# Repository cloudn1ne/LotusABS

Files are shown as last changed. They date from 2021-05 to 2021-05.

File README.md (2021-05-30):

# LotusABS

<table border=0>
<tr>
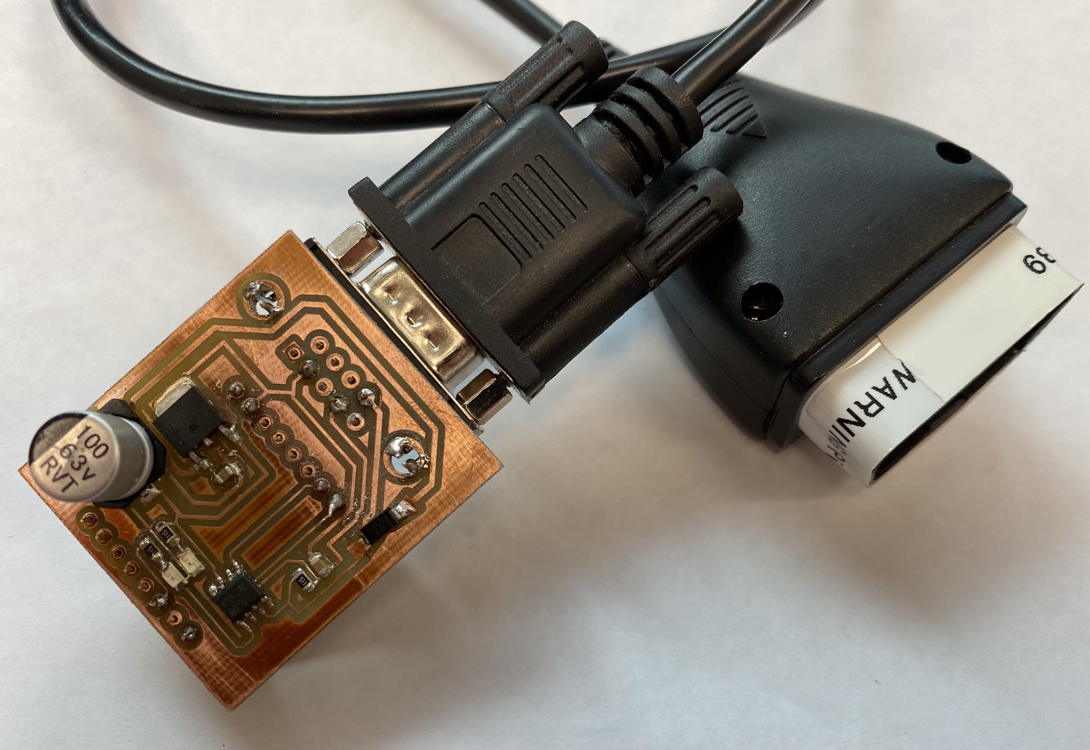
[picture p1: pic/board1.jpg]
<td></td>
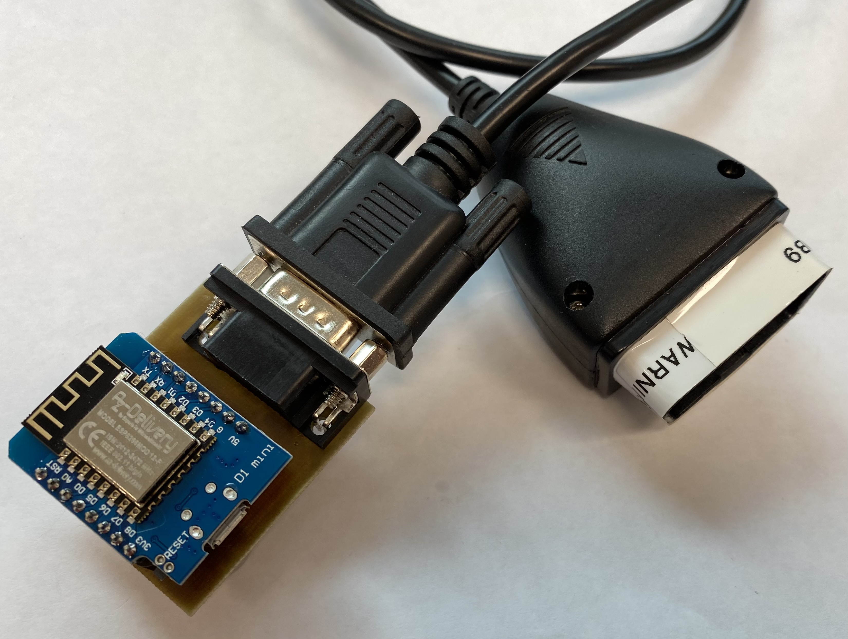
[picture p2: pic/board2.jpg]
<td colspan=2></td>
</tr><tr>
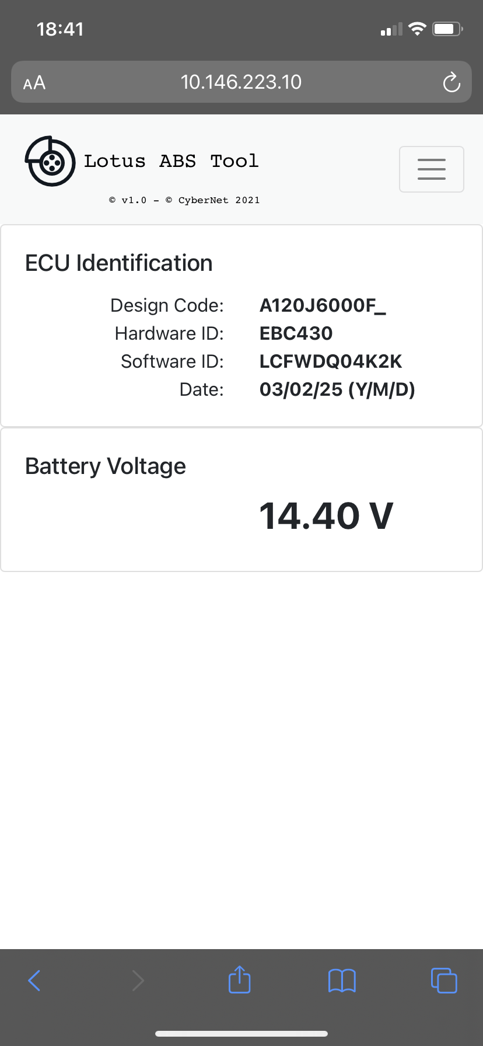
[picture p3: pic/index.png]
<td></td>
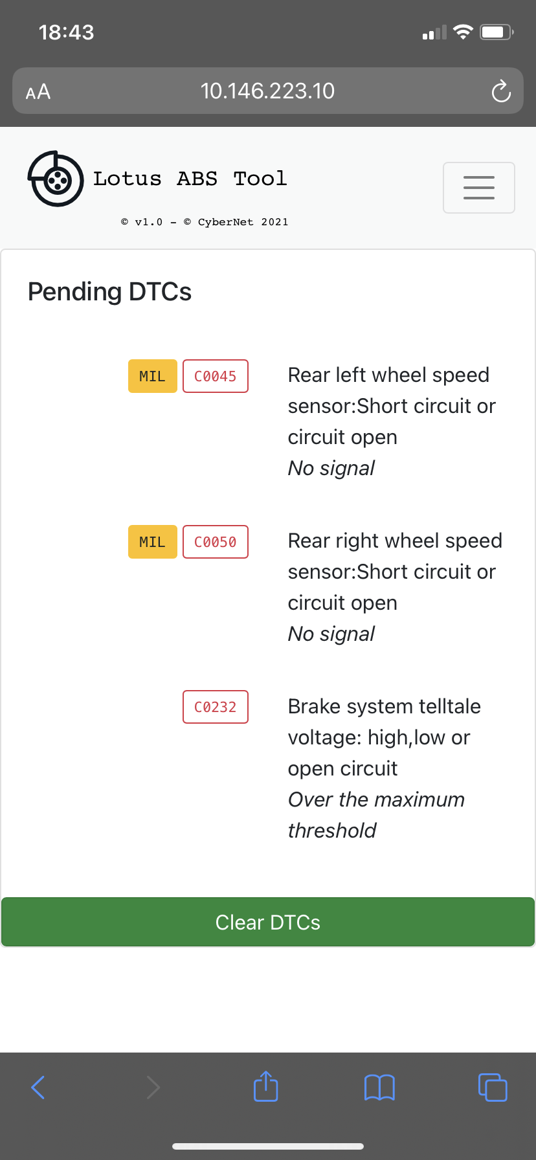
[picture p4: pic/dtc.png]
<td></td>
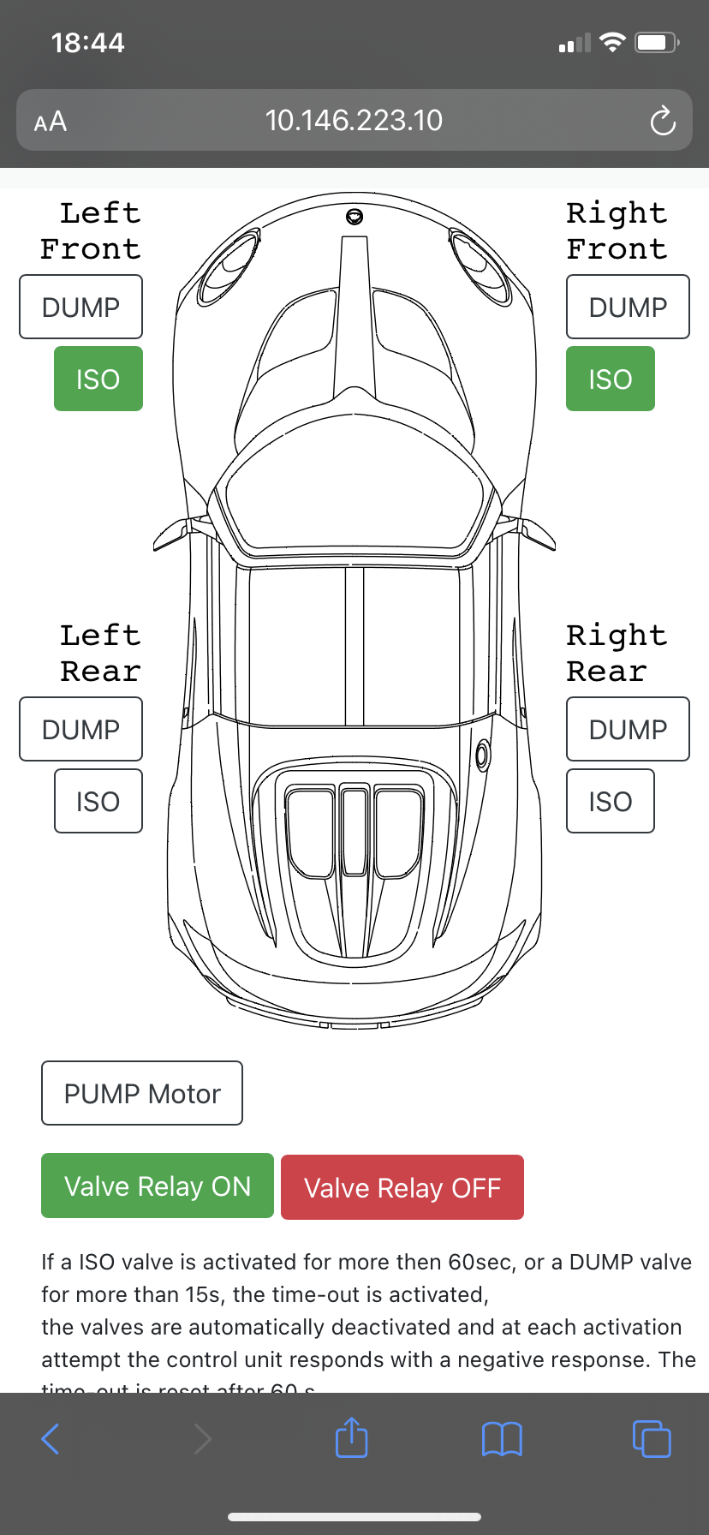
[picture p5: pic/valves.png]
<td></td>
</tr>
</table>

## What can you do with it ?

The software part is a pretty minimum implementation of the KWP2000 via K-LINE as used by the EBC430 EBC.
The supported Service IDs are:

Function | Usage
-------- | -----
StartCommunication | start a KWP2000 session
ReadECUIdentification | ECU details, nothing new here - same as listed in the Lotus Service Manual
ReadDataByLocalId | battery voltage, wheel speeds (not implemented, because my car is not moving atm)
ReadDiagnosticTroubleCodeByStatus | read DTC codes and status reasons
ClearDiagnosticInformationService | clear and DTCs
InputOutputControlByLocalId | control the valves, pump, relay

So with that you can establish communication with the ECU, get software/hardware versions, battery voltage (wheels speeds later on), read and clear DTCs, and most importantly
control the valves, pump and valve relay to aid with bleeding.

## How can i use it ?

You need to solder up the little ESP8266 based adapter (or put it on breadboard if you are adventurous. A proven PCB design and circuit is included in the ./pcb folder.
It was made with KiCAD (www.kicad.org)

## Whats the difference to existing KLINE/OBD Tools ?

Not much - i didnt have one, so i had to roll my own - the most notible difference is that the KLINE line has to be on PIN #12 of the OBD connector (usualy it would be Pin #7)
And you wont have a GUI to control stuff.

## Software
The project is based on PLATFORM.IO - download VS Code and install platform IO (https://platformio.org/) 

## Hardware
see KiCAD

### As usual that tool comes with no warranty, it might blow up your airbags (same KLINE) or set your car on fire. Good luck ;-)

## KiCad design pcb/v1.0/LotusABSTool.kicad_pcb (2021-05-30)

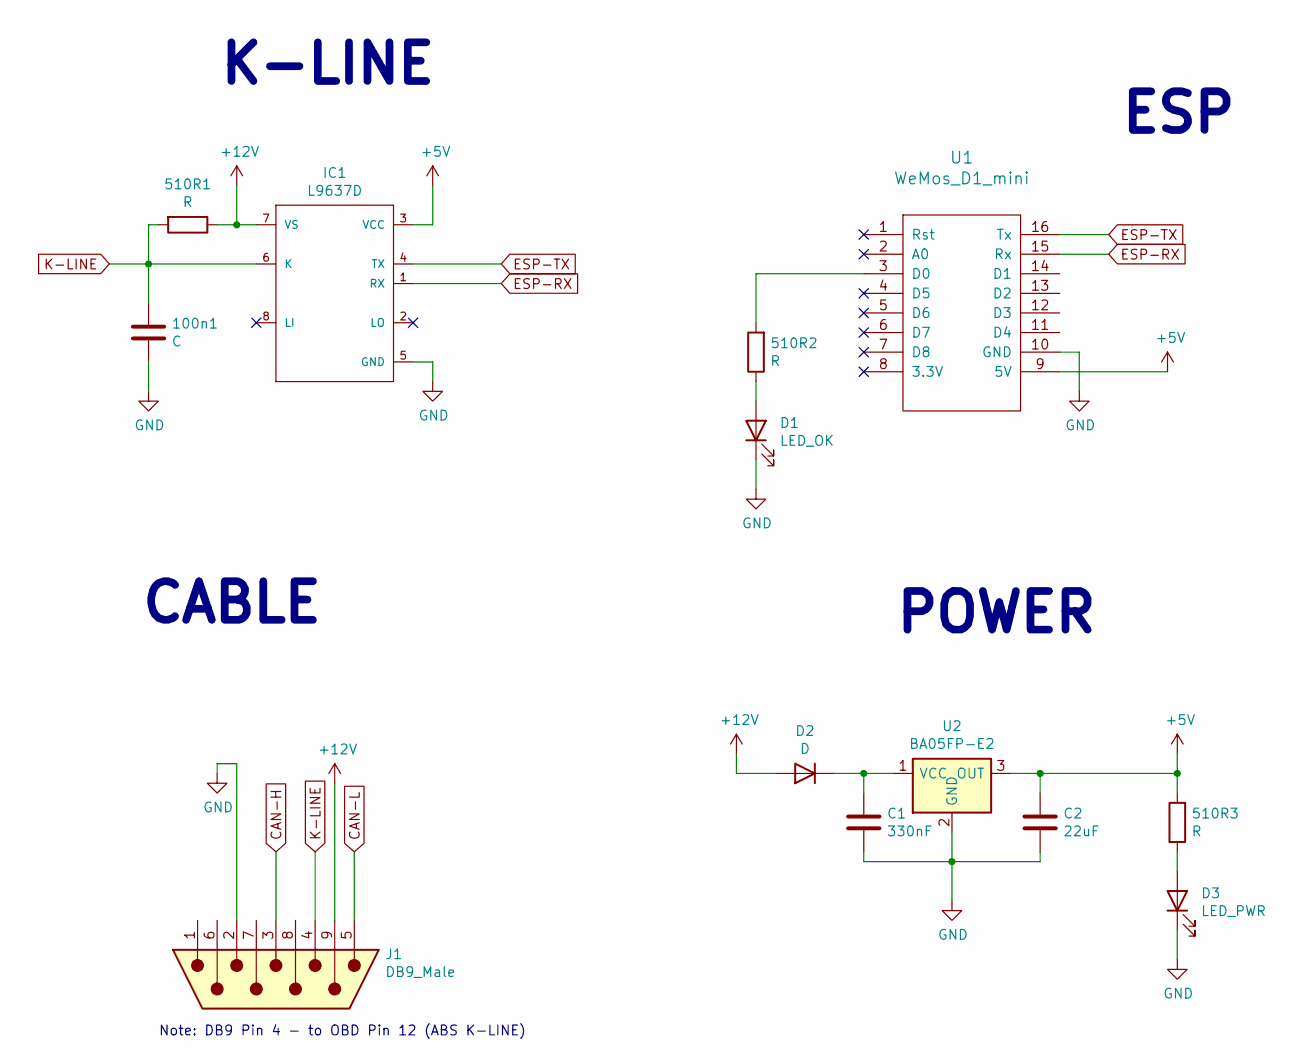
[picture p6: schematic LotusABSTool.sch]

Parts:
100n1: C; C_0805_2012Metric_Pad1.18x1.45mm_HandSolder
510R1, 510R2, 510R3: R; R_0805_2012Metric_Pad1.20x1.40mm_HandSolder
C1: 330nF; C_0805_2012Metric_Pad1.18x1.45mm_HandSolder
C2: 22uF; CP_Elec_10x10.5
D1: LED_OK; LED_0805_2012Metric_Pad1.15x1.40mm_HandSolder
D2: D; D_SMA-SMB_Universal_Handsoldering
D3: LED_PWR; LED_0805_2012Metric_Pad1.15x1.40mm_HandSolder
IC1: L9637D; SO-8_3.9x4.9mm_P1.27mm
J1: DB9_Male; DSUB-9_Male_Vertical_P2.77x2.84mm_MountingHoles
U1: WeMos_D1_mini; wemos-d1-mini-with-pin-header
U2: BA05FP-E2; TO-252-2

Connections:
+5V: 510R3.2, C2.1, IC1.3 (VCC), U1.9 (5V), U2.3 (OUT)
+12V: 510R1.1, D2.2 (A), IC1.7 (VS), J1.9
CAN-H: J1.3
CAN-L: J1.5
ESP-RX: IC1.1 (RX), U1.15 (Rx)
ESP-TX: IC1.4 (TX), U1.16 (Tx)
GND: 100n1.2, C1.2, C2.2, D1.1 (K), D3.1 (K), IC1.5 (GND), J1.2, U1.10 (GND), U2.2 (GND)
K-LINE: 100n1.1, 510R1.2, IC1.6 (K), J1.4
unnamed: 510R2.1, D1.2 (A)
unnamed: 510R2.2, U1.3 (D0)
unnamed: 510R3.1, D3.2 (A)
unnamed: C1.1, D2.1 (K), U2.1 (VCC)

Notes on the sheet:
K-LINE
ESP
POWER
CABLE
Note: DB9 Pin 4 - to OBD Pin 12 (ABS K-LINE)

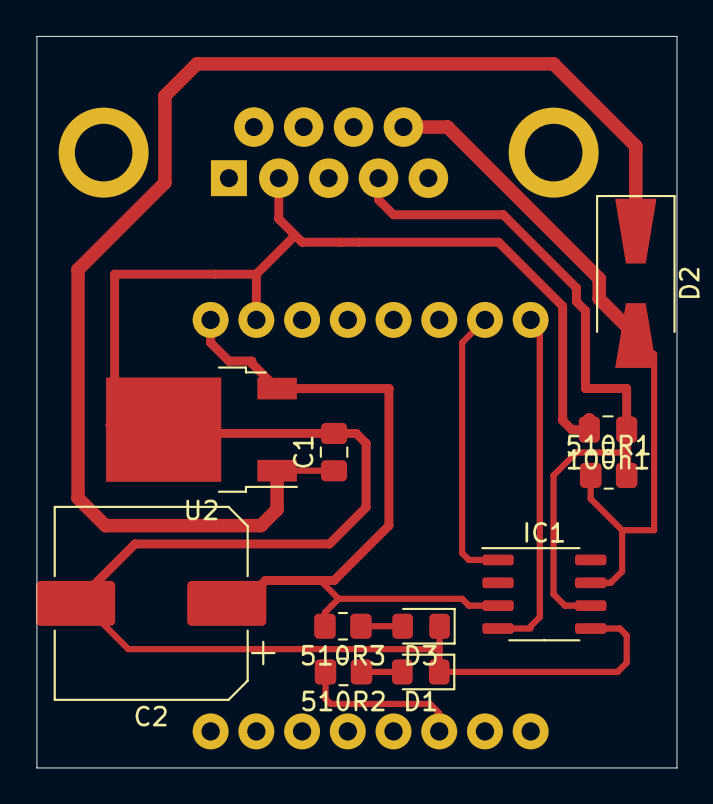
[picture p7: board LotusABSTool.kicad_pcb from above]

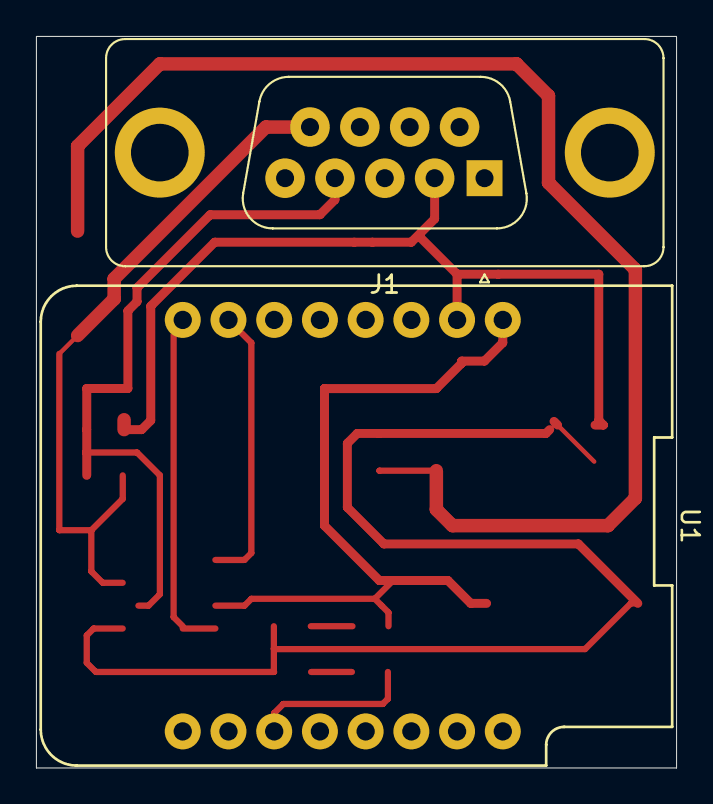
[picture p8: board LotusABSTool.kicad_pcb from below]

Board: 2 copper layers, 35.6 x 40.6 mm, 13 parts (2 on the bottom side), 10 nets.

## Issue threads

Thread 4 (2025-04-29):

D2 value / BOM

st80356, 2025-04-29:
Hello , thank you for sharing this project!  Could you provide the type of diode used for D2 and/or a BOM?  I'm having trouble identifying D2 from the photo.

cloudn1ne, 2025-05-05:
anything like a 1n4001 SMD equivalent will work, i just reused some random diode from another junk pcb. its just a reverse polarity protection.

st80356, 2025-05-05:
Awesome, thank you so much for the reply!

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

Closed 2025-05-26.

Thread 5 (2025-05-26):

Communication with 06 T4e ECU

st80356, 2025-05-26:
Hello,

I built the cable but I'm getting an "Unknown KWP 2000 error 0xff".

Are there any hardware and/or software modifications to get the cable to work with an '06 T4e ECU?

I'm pretty sure everything was assembled correctly.   The only think I can think of was maybe the DB9 to OBD cable if it should be compatible as described.

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

Could you confirm which pins to check?

Thank you for your advice!

Closed 2025-05-27.

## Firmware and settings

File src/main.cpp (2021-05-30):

/*
 * Lotus ABS ECU Tool
 * (c) Georg Swoboda, 2021
 *
 * >> Init Wifi, Main Loop, Handle Websockets <<
 */

#include <Arduino.h>
#include <SoftwareSerial.h>
#include <FS.h>     
#include <TaskScheduler.h>
#include <stdint.h>
#include <LittleFS.h>
#include <ElegantOTA.h>

#include "web.h"
#include "kwp.h"
#include "mqtt.h"
#include "log.h"
#include "ebc430.h"

#define WIFI_AP_SSID  "LOTUS-ABS"
#define WIFI_AP_PASS  ""
const byte DNS_PORT = 53;
IPAddress apIP(192, 168, 1, 1);
DNSServer dnsServer;

//#define WIFI_DEBUG 0   // enable this and set WIFI_JOIN_SSID and WIFI_JOIN_PW to join an AP (handy for debugging)
#ifdef WIFI_DEBUG
 #define WIFI_JOIN_SSID "cloud9"
 #define WIFI_JOIN_PW ""
#endif

#define TX 1
#define RX 3
#define LED_OK  16
KWP2K ABS(TX, RX);


ESP8266WebServer server(80);
WebSocketsServer ws_server = WebSocketsServer(81);

Scheduler Taskrunner;
void OKLEDTaskCallback();
Task OKLEDTask(1000, -1, &OKLEDTaskCallback);

bool state_ok_led = true;

// uint8_t ecu_addr_glob = 0x1;

void webSocketEvent(uint8_t num, WStype_t type, uint8_t * payload, size_t length) 
{
    DynamicJsonDocument json(128);
    switch(type) {
        case WStype_DISCONNECTED:
#ifdef DBG_WEBSOCKETS                    
            log_msg("webSocketEvent() [%u] Disconnected!\n", num);
#endif            
            break;
        case WStype_CONNECTED:
            {
                IPAddress ip = ws_server.remoteIP(num);
#ifdef DBG_WEBSOCKETS                            
                log_msg("webSocketEvent() [%u] Connected from %d.%d.%d.%d url: %s\n", num, ip[0], ip[1], ip[2], ip[3], payload);
#endif                
      //          ws_server.sendTXT(num, "Connected");
            }
            break;
        case WStype_TEXT:        
#ifdef DBG_WEBSOCKETS                    
            log_msg("webSocketEvent() [%u] get Text: %s\n", num, payload);
#endif            
            deserializeJson(json, payload);       
#ifdef DBG_WEBSOCKETS            
            log_msg("\t Calling SId: %02x", json["sid"].as<int>());     
#endif            
            switch (json["sid"].as<int>())          
            {
                case KWP_SID_STARTCOMMUNICATION:                  ABS.StartCommunication(); break;
                case KWP_SID_READECUIDENTIFICATION:               ABS.ReadECUIdentification(json["option"].as<int>()); break;
                case KWP_SID_READDIAGNOSTICTROUBLECODESBYSTATUS:  ABS.ReadDiagnosticTroubleCodesByStatus(); break;
                case KWP_SID_CLEARDIAGNOSTICINFORMATIONSERVICE:   ABS.ClearDiagnosticInformationService(); break;
                case KWP_SID_READDATABYLOCALID:                   ABS.ReadDataByLocalId(json["record"].as<int>(), json["dtc"].as<int>()); break;
                case KWP_SID_INPUTOUTPUTCONTROLBYLOCALID:         ABS.InputOutputControlByLocalId(json["id"].as<int>(), json["ctrl_param"].as<int>(), json["ctrl_state"].as<int>()); break;
                default:
#ifdef DBG_WEBSOCKETS                            
                          log_msg("\n unknown SiD, no function defined ?");
#endif                           
                          break;
            }
            break;        
    }

}

void setup() {

  // Taskrunner
  Taskrunner.init();
  Taskrunner.addTask(OKLEDTask);
  
  // Setup Serial
  Serial.begin(10400);
  
  // SETUP WiFI (Normal AP Mode)
#ifndef WIFI_DEBUG   
  WiFi.mode(WIFI_AP);
  WiFi.softAPConfig(apIP, apIP, IPAddress(255, 255, 255, 0));
  boolean state = WiFi.softAP(WIFI_AP_SSID,WIFI_AP_PASS);
  while (!state) {
    Serial.println("Creating access point failed");
    // don't continue - WD will kill us
    while (true);
  }
  dnsServer.start(DNS_PORT, "*", apIP);  
#else
  // (Debug join AP Mode)
  WiFi.mode(WIFI_STA);  
  WiFi.begin("CLOUD9", "deepspace48");  
  while (WiFi.status() != WL_CONNECTED) {
    delay(500);
    Serial.print(".");
  }
  Serial.printf("\n===================================\nLotusABS IP address is: %d.%d.%d.%d\n", WiFi.localIP()[0], WiFi.localIP()[1], WiFi.localIP()[2], WiFi.localIP()[3]);  
#endif

  mqtt_setup();
  log_msg("\n===================================\nLotusABS IP address is: %d.%d.%d.%d\n", WiFi.localIP()[0], WiFi.localIP()[1], WiFi.localIP()[2], WiFi.localIP()[3]);
  
  // SETUP WWW
  if (!LittleFS.begin())
  {
    Serial.println("unable to init LittleFS");
  }
  server.serveStatic("/", LittleFS, "/www/index.html");
  server.serveStatic("/valves.html", LittleFS, "/www/valves.html");
  server.serveStatic("/dtc.html", LittleFS, "/www/dtc.html");
  server.serveStatic("/js", LittleFS, "/www/js");
  server.serveStatic("/img", LittleFS, "/www/img");
  server.serveStatic("/css", LittleFS, "/www/css");

  server.on("/ReadECUIdentification", HTTP_GET, []() {            
      uint8_t option = EBC_OPT_ALL;
      if (server.hasArg("option"))
      {
          option = server.arg("option").toInt();                                       
         
      }  
      ABS.ReadECUIdentification(option);          
      server.send(200, "application/json", "{ \"status\" : true }");
  });


  // AsyncElegantOTA.begin(&server);
  ElegantOTA.begin(&server); 
  server.begin();

  // register ABS ECU callbacks
  ABS.setTimeoutCallback(&TimeoutCB);
  ABS.setCallback(KWP_SID_ERR, &ErrorMessageCB);
  ABS.setCallback(KWP_SID_STARTCOMMUNICATION, &StartCommunicationCB);
  ABS.setCallback(KWP_SID_READECUIDENTIFICATION, &ReadECUIdentificationCB);
  ABS.setCallback(KWP_SID_READDATABYLOCALID, &ReadDataByLocalIdCB);
  ABS.setCallback(KWP_SID_READDIAGNOSTICTROUBLECODESBYSTATUS, &ReadDiagnosticTroubleCodeByStatusCB);
  ABS.setCallback(KWP_SID_CLEARDIAGNOSTICINFORMATIONSERVICE, &ClearDiagnosticInformationServiceCB);
  ABS.setCallback(KWP_SID_INPUTOUTPUTCONTROLBYLOCALID, &InputOutputControlByLocalIdCB);

  // SETUP Pins
  pinMode(LED_OK, OUTPUT);  
  
  // enable Tasks
  OKLEDTask.enable();  

  // enable webSockets
    ws_server.begin();
    ws_server.onEvent(webSocketEvent);
}

// not that useful, but everybody likes blinkenlights ;)
// might use that for something else one day
void OKLEDTaskCallback()
{  
  digitalWrite(LED_OK, state_ok_led);
  state_ok_led = !state_ok_led;
}

void loop() {

  mqtt_loop();
  ABS.process(); 
  Taskrunner.execute();
  server.handleClient();
  ws_server.loop();
#ifndef WIFI_DEBUG    
  dnsServer.processNextRequest();
#endif
}

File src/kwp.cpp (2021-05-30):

/*
 * Lotus ABS ECU Tool
 * (c) Georg Swoboda, 2021
 *
 * >> Poor mans KWP2k implementation, as async as possible to not waste any cycles while waiting <<
 */

#include <Arduino.h>
#include "kwp.h"
#include "log.h"

// constructor and overloads
KWP2K::KWP2K(uint8_t tx_pin, uint8_t rx_pin)
{
    _tx_pin = tx_pin;
    _rx_pin = rx_pin;
    _ECUaddress = KWP2k_DEFAULT_ECUADDRESS;
    _Testeraddress = KWP2K_DEFAULT_TESTERADDRESS;
    _ser =  new SoftwareSerial(_rx_pin, _tx_pin);
    _ser->begin(KWP2K_BAUDRATE);
    this->resetFlags();
}

KWP2K::KWP2K(uint8_t tx_pin, uint8_t rx_pin, uint8_t ECUaddress)
{
    _tx_pin = tx_pin;
    _rx_pin = rx_pin;
    _ECUaddress = ECUaddress;
    _Testeraddress = KWP2K_DEFAULT_TESTERADDRESS;
    _ser =  new SoftwareSerial(_rx_pin, _tx_pin);
    _ser->begin(KWP2K_BAUDRATE);
    this->resetFlags();
}

KWP2K::KWP2K(uint8_t tx_pin, uint8_t rx_pin, uint8_t ECUaddress, uint8_t Testeraddress)
{
    _tx_pin = tx_pin;
    _rx_pin = rx_pin;
    _ECUaddress = ECUaddress;
    _Testeraddress = Testeraddress;
    _ser =  new SoftwareSerial(_rx_pin, _tx_pin);
    _ser->begin(KWP2K_BAUDRATE);
    this->resetFlags();        
}

void KWP2K::resetFlags()
{
    _is_initialized = false;
    _is_communication_started = false;
    _last_tx_msg_ts = 0;           // never    
    _last_rx_msg_ts = 0;           // never

    // reset tx queue to be empty
    for (uint8_t i=0;i<KWP2K_TX_QUEUE_SIZE;i++)
    {
        _tx_queue[i]=NULL;
    }
    _waiting_for_reply = false;    
}

void KWP2K::setTimeoutCallback(void (*callback)(void))
{
    cb_Timeout = callback;
}

void KWP2K::setCallback(uint8_t SId, void (*callback)(uint8_t *payload_bytes, uint8_t payload_len))
{
    switch (SId)
    {        
        case KWP_SID_ERR:                                   cb_ErrorMessage                         = callback; break;
        case KWP_SID_STARTCOMMUNICATION:                    cb_StartCommunication                   = callback; break;
        case KWP_SID_READECUIDENTIFICATION:                 cb_ReadECUIdentification                = callback; break;
        case KWP_SID_READDATABYLOCALID:                     cb_ReadDataByLocalId                    = callback; break;
        case KWP_SID_READDIAGNOSTICTROUBLECODESBYSTATUS:    cb_ReadDiagnosticTroubleCodesByStatus   = callback; break;
        case KWP_SID_CLEARDIAGNOSTICINFORMATIONSERVICE:     cb_ClearDiagnosticInformationService    = callback; break;
        case KWP_SID_INPUTOUTPUTCONTROLBYLOCALID:           cb_InputOutputControlByLocalId          = callback; break;
    }
}

/*
* add KWP2KMsg to TX queue
*/
bool KWP2K::pushTXQueue(KWP2KMsg *msg)
{
#ifdef DBG_KWP2K
        log_msg("KWP2K::addToTXQueue(SId=%02x)\n", msg->getSId());      
#endif      
    uint8_t i;

    for (i=0;i<KWP2K_TX_QUEUE_SIZE;i++)
    if (_tx_queue[i] == NULL)
    {
        _tx_queue[i] = msg;
#ifdef DBG_KWP2K
        log_msg("\t added to slot #%d\n", i);      
#endif     
        return(true);
    }       
#ifdef DBG_KWP2K
        log_msg("\t ERROR no emtpy queue slot found\n");  
#endif  
    return(false);   
}

/*
* pop KWP2KMsg from TX queue
* return: NULL or a KWP2K message if one is pending to be sent
*/
KWP2KMsg *KWP2K::popTXQueue(void)
{  
    uint8_t i;
    KWP2KMsg *retptr;

    for (i=0;i<KWP2K_TX_QUEUE_SIZE;i++)
    if (_tx_queue[i] != NULL)
    {
        retptr = _tx_queue[i];
        _tx_queue[i] = NULL;     // mark empty        
#ifdef DBG_KWP2K
        log_msg("KWP2K::popTXQueue()\n"); 
        log_msg("\t returned KWP2KMsg (SId=%02x) from slot #%d\n", retptr->getSId(), i);      
#endif     
        return(retptr);
    }       
    return(NULL);   
}

/*
* peek KWP2KMsg in TX queue
* return: true if some message wants to be send, otherwise false
*/
KWP2KMsg *KWP2K::peekTXQueue(void)
{  
    uint8_t i;
    
    for (i=0;i<KWP2K_TX_QUEUE_SIZE;i++)
    if (_tx_queue[i] != NULL)
    {
      return(_tx_queue[i]);
    }       
    return(NULL);   
}

//////////////////////////////////////////////
// Process KWP2K Handler
//////////////////////////////////////////////
void KWP2K::process()
{      
    KWP2KMsg *msg;
    
    // should we trigger a fastInit ?
    if (_is_initialized && (_last_tx_msg_ts+KWP2K_SESSION_TIMEOUT < millis()))
    {
#ifdef DBG_KWP2K
        log_msg("KWP2K::process() no longer initialized\n");      
#endif  
        _is_initialized = false;           // Communication Session no longer initialized
        _is_communication_started = false; // Communication Session timed out        
    }            

    // we are not waiting for a reply to a previous message and there is a new one to send
    // if (!_waiting_for_reply && (msg=this->popTXQueue()))    


    if ( (_last_rx_msg_ts+KWP2K_INTERMSG_DELAY < millis() ) &&      // wait for intermessage delay (between last rx and next tx)
         !_waiting_for_reply &&                                     // we dont have a reply that we expect pending
         this->peekTXQueue()                                        // there is a new message waiting to be sent
       )    // message to be sent pending ?
    {    
        // are we initalized ? 
        if (!_is_initialized)
        {
            this->fastInit();
        }                
        // do we have a comm session
        if (!_is_communication_started && (this->peekTXQueue()->getSId()!=KWP_SID_STARTCOMMUNICATION))
        {                        
            msg = this->getStartCommunicationMsg();       // send the StartCommunication message
        }
        else
        {
            msg = this->popTXQueue();                   // send the pending message
        }
        
        this->sendMsg(msg);                                
        delete msg;

        _waiting_for_reply_timeout = millis();
        _waiting_for_reply = true;

        _msgrx.reset();         // make ready the _msgrx buffer                
    }

    // are we waiting for a reply ?
    if (_waiting_for_reply)
    {               
        // have we been waiting too long ?
        if (_waiting_for_reply_timeout + KWP2K_REPLY_TIMEOUT < millis())
        {
            _waiting_for_reply = false; 
            _is_communication_started = false;
            _is_initialized = false;
            this->cb_Timeout(); 
            log_msg("WARNING: expected reply timed out\n");
        }
        else
        {
            // attempt to receive reply from ECU
            _msgrx.setState(IDLE);
            while (_ser->available())
            {                
                uint8_t in = _ser->read();      
                _msgrx.rxByte(in);
                _last_rx_msg_ts = millis();
            }       
        }                        
    }
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

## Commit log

2021-05-25 voltage reading also works
2021-05-26 fixed KWP2k handling when reconnecting, and implemented DTC list/clear functions
    [kwp.cpp, main.cpp]
2021-05-28 valve control working
2021-05-28 added ErrorReporting to all pages
    [main.cpp]
2021-05-30 added kicad v1.0
